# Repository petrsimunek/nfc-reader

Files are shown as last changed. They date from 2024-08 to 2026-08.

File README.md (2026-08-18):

# NFC Reader

NFC card reader with display, HID functionality and 3D printed case.

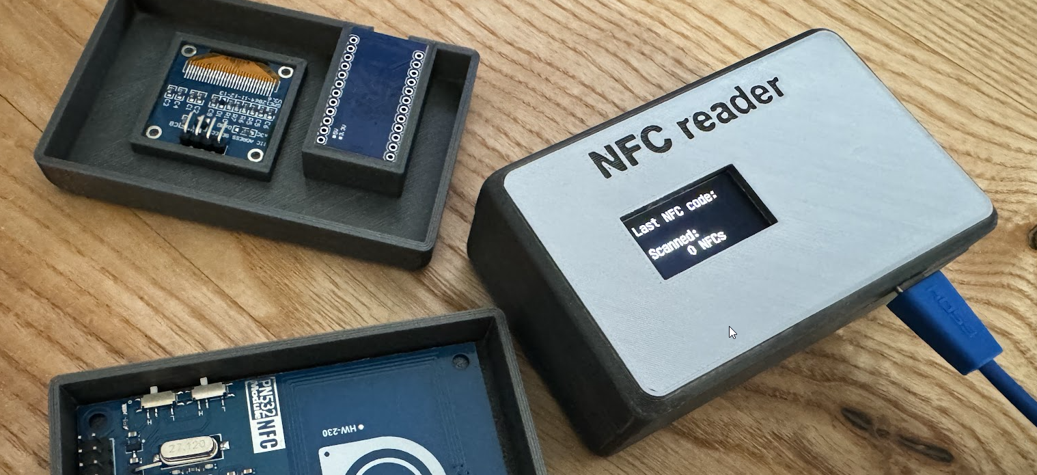
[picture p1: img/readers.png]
readers


## Motivation & backstory

User who is maintaining EV chargers asked for a simple tool, where he would be able to see card or chip number instantly. Chips comes sometimes with the number engraved on it, but some suppliers delivers cards without numbers.

So our user had to go to the EV charger, beep the card, go back to computer, and check the EV management for the "unauthorized card".

He asked for a solution, which would show him the number, and/or put the number to the computer.

I tried USB/NFC readers, or some flipper-like devices, but those were too complicated.

## How it works

Solution is built on arduino with NFC reader and simple display. User scan the card, and the number is displayed. The arduino has the HID feature enabled, so it directly inputs the card number to the connected computer, followed by TAB key.

SIMPLE!

## What is needed

- Arduino (pick model which supports HID feature - Arduino Pro Micro ATmega32U4 5V 16MHz) [link](https://dratek.cz/arduino/960-leonardo-pro-micro.html)
- PN532 NFC card reader [link](https://dratek.cz/arduino/2005-rfid-ic-ctecka-karet-13.56mhz-modul-pro-arduino-pn532-nfc.html)
- 1,3'' OLED display [link](https://dratek.cz/arduino-platforma/3181-iic-i2c-oled-1-3-displej-128x64-bily.html)
- microUSB cable

Plus

- Common tools + tool for soldering
- 3D printer
- Glue

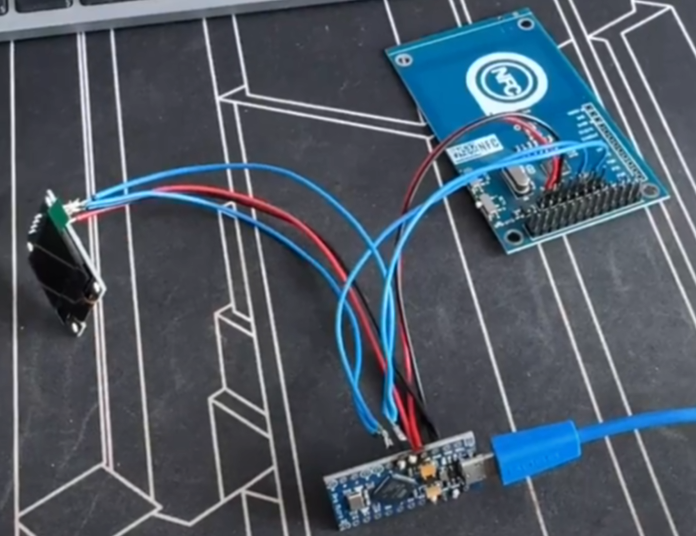
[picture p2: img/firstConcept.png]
first concept


## Wiring

Both the PN532 NFC reader and the OLED display share the same I2C bus on the Arduino Pro Micro. Set the PN532 module to **I2C mode** using its onboard switches before powering up.

### Arduino Pro Micro pins

| Function | Pin |
| --- | --- |
| SDA | **2** |
| SCL | **3** |
| VCC | **5V** |
| GND | **GND** |

### OLED display (I2C)

| OLED | Pro Micro |
| --- | --- |
| VCC | 5V |
| GND | GND |
| SDA | 2 (SDA) |
| SCK / SCL | 3 (SCL) |

### PN532 NFC reader (I2C)

| PN532 | Pro Micro |
| --- | --- |
| VCC | 5V |
| GND | GND |
| SDA | 2 (SDA) |
| SCL | 3 (SCL) |

Connect both modules in parallel on the I2C lines (SDA/SCL) and power rails (5V/GND). No other GPIO pins are used for the display or NFC reader.

## Change configuration

For any configuration changes you can run the `configurater/index.html` file. It is simple webpage with javascript inside. The javascript opens serial communication with the connected reader, and provides you simple GUI to change basic settings of the reader.

### Things you can configure

- enable/disable sending code to the computer
- keyboard mode
  - EN - use with top row keys
  - CS - use top row keys with Shift pressed (usable for national specific keyboard layouts)
  - NUMPAD - use numpad keys - might not work on laptops
- code mode - format of the code sent to the PC / shown on display
  - UID - full UID as hexadecimal (e.g. `04A3B21F`)
  - EVCH - full UID as decimal number
  - ADAM - first three UID bytes reversed into a 24-bit value, sent as decimal
  - CARD - sends UID, EVCH and ADAM one after another, with the configured key (TAB/ENTER/ESC) between them
- double read protection - if enabled, it won't allow you to read the same card again for 10 seconds - it avoids sending the same card twice to the PC
- enable/disable sending key after the code
- define the key which should be sent after the code
  - TAB
  - ESC
  - ENTER

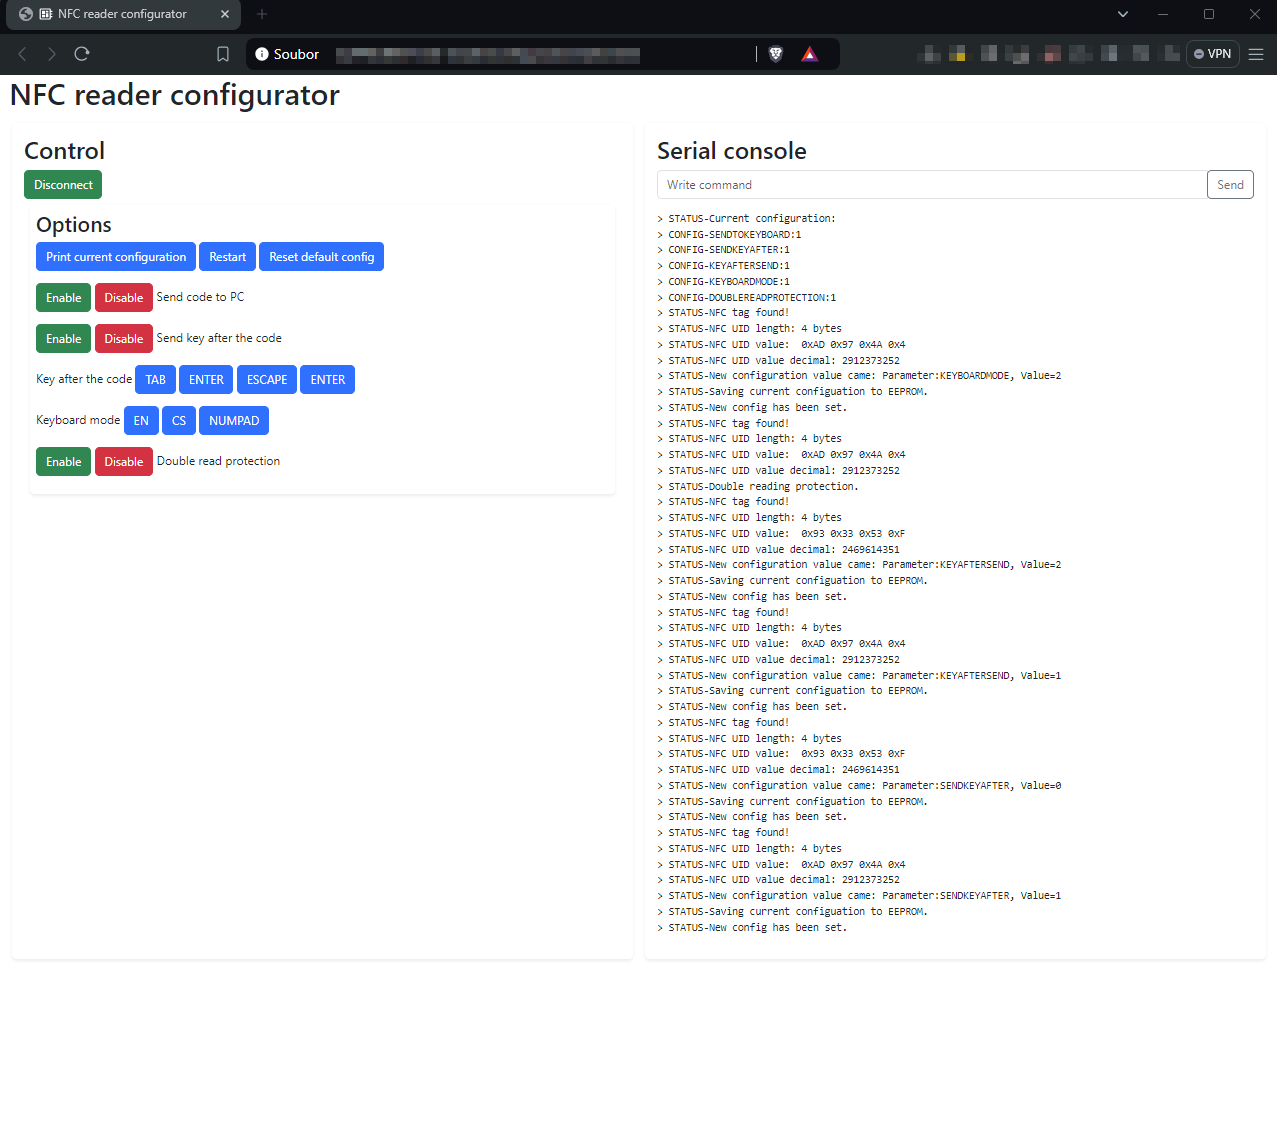
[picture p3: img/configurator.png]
configurator


## Case

Case can be printed on any 3D printer. There is no tricky part. Place the casing the text facing down on the heatbed.

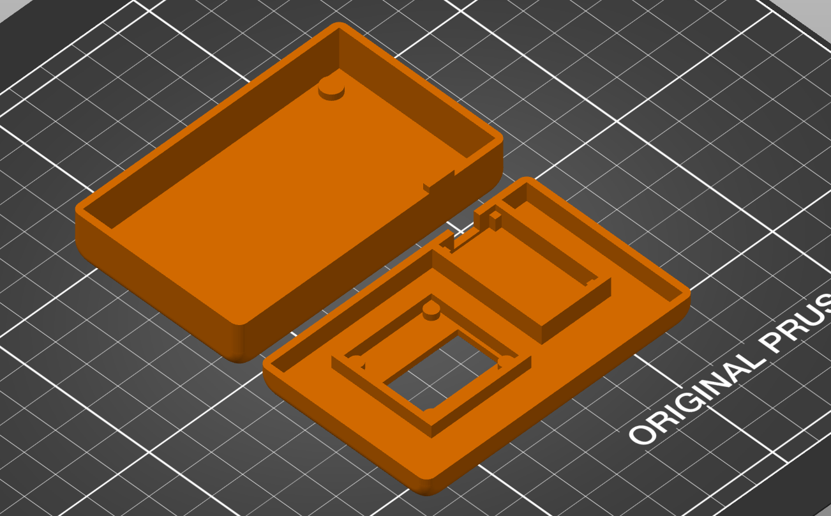
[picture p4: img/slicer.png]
slicer


Parameters for print:

- PLA (or any material) < tested on PLA
- no supports
- heating based on the material - default

For multicolor printing enable filament change in your slicer after the first layer.

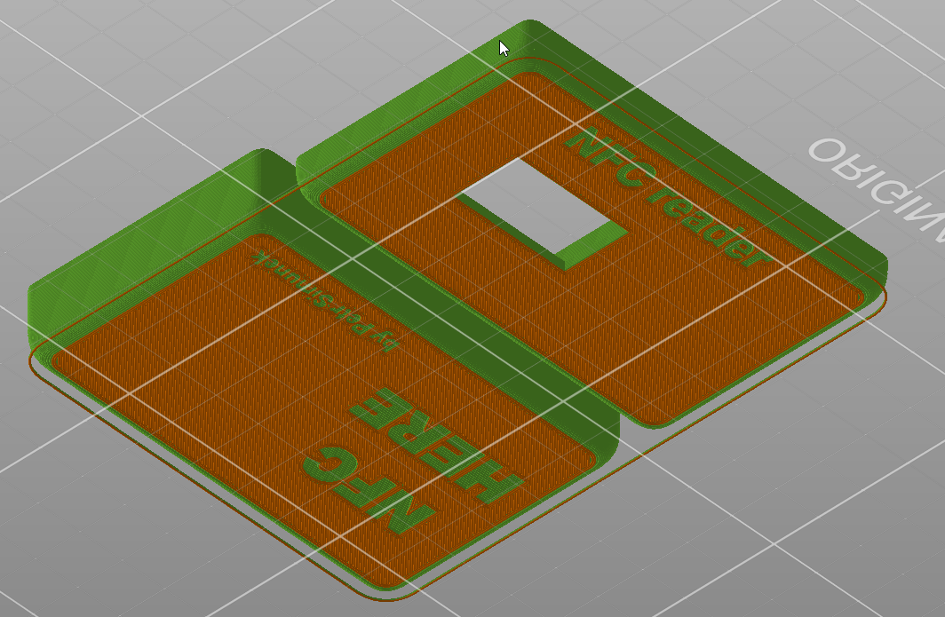
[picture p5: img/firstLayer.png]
first layer


## Troubleshooting

Basic debug can be done through serial console. Use serial monitor in arduino IDE, or putty.

If something do not work, check cabling, soldering, configuration through the configurator and num lock on your keyboard.

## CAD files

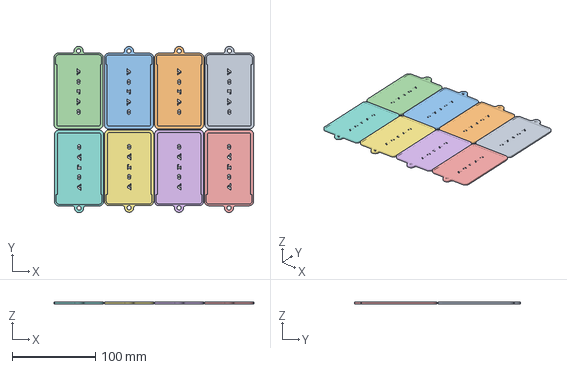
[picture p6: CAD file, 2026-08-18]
card_cover/cover.3mf
239.8 x 199.4 x 2.50 mm
Part Studio 1 - obal.stl x 2

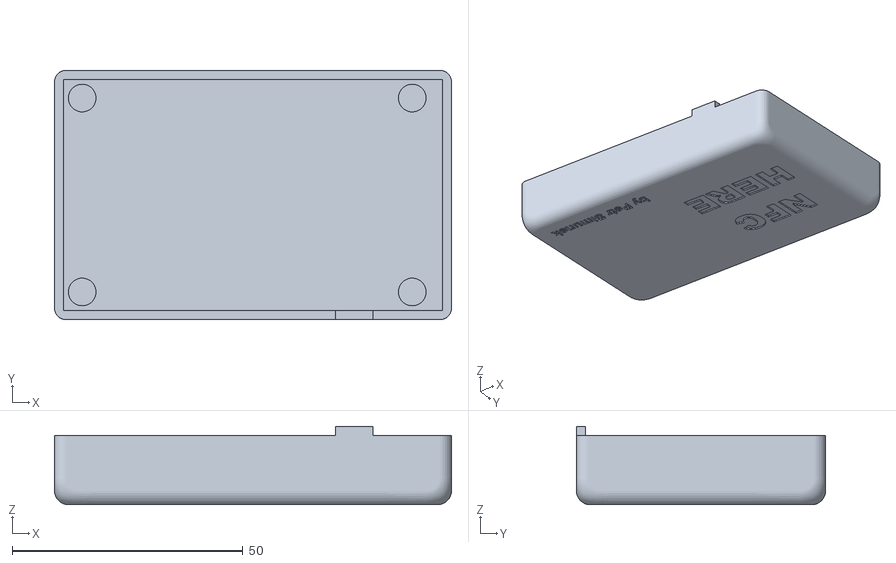
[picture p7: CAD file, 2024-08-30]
case/nfc_bottom_LP.stl
86.0 x 54.0 x 17.0

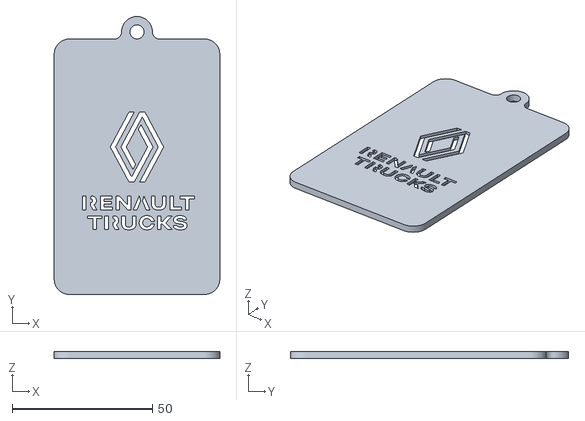
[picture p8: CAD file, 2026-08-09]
card_cover/cover-RT.stl
59.0 x 99.0 x 2.50

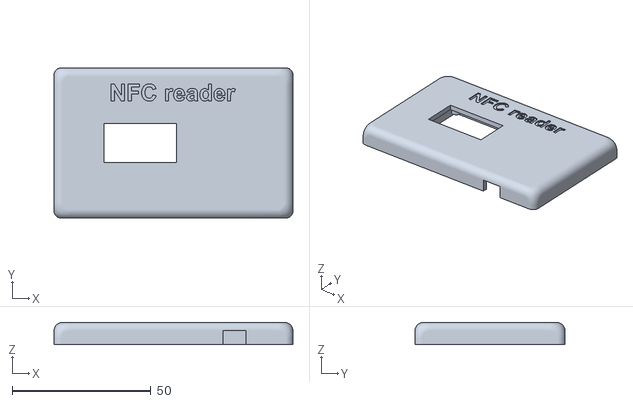
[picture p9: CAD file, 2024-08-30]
case/nfc_top_LP.stl
86.0 x 54.0 x 8.00

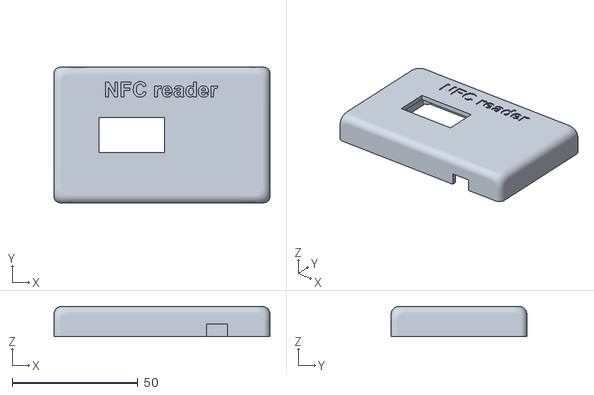
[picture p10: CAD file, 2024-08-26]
case/nfc_top.stl
86.0 x 54.0 x 12.0

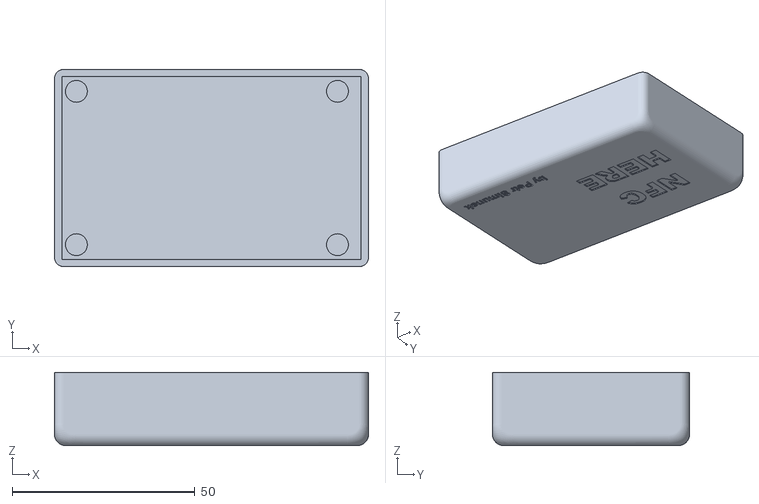
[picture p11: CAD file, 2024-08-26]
case/nfc_bottom.stl
86.0 x 54.0 x 20.0

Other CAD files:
card_cover/cover-VT.stl

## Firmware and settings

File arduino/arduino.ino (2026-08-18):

// include libs
#include <PN532_I2C.h>
#include <PN532.h>
#include <NfcAdapter.h>
#include <Keyboard.h>
#include <U8glib.h>
#include <avr/wdt.h>

// Version lives in configurator/version.js so the web UI and firmware share it.
#define EXPECTED_FIRMWARE_VERSION const char firmwareVersion[]
#if __has_include("../configurator/version.js")
#include "../configurator/version.js"
#elif __has_include("version.h")
#include "version.h"
#else
#include "version.js"
#endif
#undef EXPECTED_FIRMWARE_VERSION


// config structure
struct config
{
  bool sendToKeyboard;
  bool sendKeyAfter;
  int keyAfterSend;
  int keyboardMode;
  bool doubleReadProtection;
  int codeMode;               // 1 = UID, 2 = EVCH, 3 = ADAM, 4 = CARD
};
// global variable for configuration
config configuration;


// init I2C communication with NFC reader
PN532_I2C pn532i2c(Wire);
// init instance of NFC reader
PN532 nfc(pn532i2c);
// init OLED display
U8GLIB_SSD1306_128X64 myOled(U8G_I2C_OPT_NONE);
unsigned long previousMillis = 0;   // timer for loop

// init var for decimal value of the NFS tag
unsigned long decimalValue = 0;       // ID in dec
String stringDecimalValue;            // ID in string
String prevStringDecimalValue;        // previous ID in string
uint8_t lastUid[10] = { 0 };
uint8_t lastUidLength = 0;







void setup() {
  // keyboard HID start
  Keyboard.begin();
  // start serial communication
  Serial.begin(9600);
  // greetings on display
  myOled.firstPage();
  do {
    displayWriteInit();
  } while( myOled.nextPage() );
  // greetings on serial after a small delay
  delay(3000);
  Serial.print("STATUS-Hello! version ");
  Serial.println(firmwareVersion);
  // init configuration
  // check first run, then set the dafults and save it to the EEPROM
  if (isFirstRun()) {
    Serial.println("STATUS-First run, writing the defaults to EEPROM.");
    setDefaultConfig();
    saveConfig();
  } else {
    loadConfig();
  }
  printCurrentConfig();
  // start NFC communication
  nfc.begin();
  // set max no of NFC read attempts
  nfc.setPassiveActivationRetries(0xFF);
  // configure NFC for reading tags
  nfc.SAMConfig();
  // debug info for user
  Serial.println("STATUS-Ready");
}







void loop() {
  // current time for timer
  unsigned long currentMillis = millis();
  //read NFC in interval
  if (currentMillis - previousMillis >= (2000)) {
    // update prev. timer
    previousMillis = currentMillis;
    // read NFC
    readNfc();
    // rewrite display
    // refresh display
    myOled.firstPage();
    do {
      displayWrite();
    } while( myOled.nextPage() );
  }
  //check new commands
  checkSerialCommands();
}







// checks serial commands
void checkSerialCommands() {
    // check
    if (Serial.available() > 0) {
        String command = Serial.readStringUntil('\n');
        command.trim();
        // run function based on command prefix
        if (command.indexOf("CONFIG-") == 0) newConfig(command);
        else if (command == "SHOWCONFIG") printCurrentConfig();
        else if (command == "SHOWNFCLAST") Serial.println(prevStringDecimalValue);
        else if (command == "RESTART") restart();
        else if (command == "RESET") reset();
        else Serial.println("Unknown command prefix");
    }
}

// function for restarting arduino
void restart() {
  Serial.println("STATUS-Restarting device");
  wdt_enable(WDTO_15MS);
  while (1) {
    // infinite loop for restarting the arduino
  }
}

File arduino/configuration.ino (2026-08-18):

#include <EEPROM.h>

bool defaultSendToKeyboard = true;
bool defaultSendKeyAfter = true;
int defaultKeyAfterSend = 1;
int defaultKeyboardMode = 1;
bool defaultDoubleReadProtection = true;
int defaultCodeMode = 2; // EVCH

// EEPROM is empty?
bool isFirstRun() {
  return EEPROM.read(0) == 0xFF;
}

// keep config values in valid ranges (e.g. after firmware upgrade)
void sanitizeConfig() {
  if (configuration.codeMode < 1 || configuration.codeMode > 4) {
    configuration.codeMode = defaultCodeMode;
  }
  if (configuration.keyboardMode < 1 || configuration.keyboardMode > 3) {
    configuration.keyboardMode = defaultKeyboardMode;
  }
  if (configuration.keyAfterSend < 1 || configuration.keyAfterSend > 3) {
    configuration.keyAfterSend = defaultKeyAfterSend;
  }
  // EEPROM bools can be 0xFF after struct changes; treat garbage as default
  if (configuration.doubleReadProtection != 0 && configuration.doubleReadProtection != 1) {
    configuration.doubleReadProtection = defaultDoubleReadProtection;
  }
  if (configuration.sendToKeyboard != 0 && configuration.sendToKeyboard != 1) {
    configuration.sendToKeyboard = defaultSendToKeyboard;
  }
  if (configuration.sendKeyAfter != 0 && configuration.sendKeyAfter != 1) {
    configuration.sendKeyAfter = defaultSendKeyAfter;
  }
}

void loadConfig() {
  EEPROM.get(1, configuration);
  sanitizeConfig();
}

// function for printing current configuration to serial console
void printCurrentConfig() {
  Serial.println("STATUS-Current configuration:");
  Serial.print("STATUS-VERSION:");
  Serial.println(firmwareVersion);
  Serial.print("CONFIG-SENDTOKEYBOARD:");
  Serial.println(configuration.sendToKeyboard);
  Serial.print("CONFIG-SENDKEYAFTER:");
  Serial.println(configuration.sendKeyAfter);
  Serial.print("CONFIG-KEYAFTERSEND:");
  Serial.println(configuration.keyAfterSend);
  Serial.print("CONFIG-KEYBOARDMODE:");
  Serial.println(configuration.keyboardMode);
  Serial.print("CONFIG-DOUBLEREADPROTECTION:");
  Serial.println(configuration.doubleReadProtection);
  Serial.print("CONFIG-CODEMODE:");
  Serial.println(configuration.codeMode);
}

// set default values to global configuration variable
void setDefaultConfig() {
  configuration.sendToKeyboard = defaultSendToKeyboard;
  configuration.sendKeyAfter = defaultSendKeyAfter;
  configuration.keyAfterSend = defaultKeyAfterSend;
  configuration.keyboardMode = defaultKeyboardMode;
  configuration.doubleReadProtection = defaultDoubleReadProtection;
  configuration.codeMode = defaultCodeMode;
}

// save the current configuration to the EEPROM
void saveConfig() {
  Serial.println("STATUS-Saving current configuation to EEPROM.");
  EEPROM.write(0, 0x00);      // set first block of EEPROM to 0 to indicate, that the configuration is there
  EEPROM.put(1, configuration);
}

// reset to defaults
void reset() {
  Serial.println("STATUS-Reseting configuration");
  EEPROM.write(0, 0xFF);  // set memory indicator
  restart();
}


void newConfig(String command) {
  Serial.print("STATUS-New configuration value came: ");
  // get rest of the command
  String remaining = command.substring(7);
  remaining.trim();
  // find colon
  int colonIndex = remaining.indexOf(':');
  if (colonIndex != -1) {
    // split to parameter and value
    String parameter = remaining.substring(0, colonIndex);
    String value = remaining.substring(colonIndex + 1);
    parameter.trim();
    value.trim();
    // serial
    Serial.print("Parameter:");
    Serial.print(parameter);
    Serial.print(", Value=");
    Serial.println(value);
    // set parameter
    if (parameter == "SENDTOKEYBOARD"){configuration.sendToKeyboard = value.toInt();}
    else if (parameter == "SENDKEYAFTER"){configuration.sendKeyAfter = value.toInt();}
    else if (parameter == "KEYAFTERSEND"){configuration.keyAfterSend = value.toInt();}
    else if (parameter == "KEYBOARDMODE"){configuration.keyboardMode = value.toInt();}
    else if (parameter == "DOUBLEREADPROTECTION"){configuration.doubleReadProtection = value.toInt();}
    else if (parameter == "CODEMODE"){configuration.codeMode = value.toInt();}
    else {Serial.println("Unknown parameter.");}
    sanitizeConfig();
    // save config to EEPROM
    saveConfig();
    Serial.println("STATUS-New config has been set.");
  }
  else {
    Serial.println("Colon not found, config command corrupted");
  }
}

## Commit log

2024-08-26 init commit
    [nfc_bottom.stl, nfc_top.stl]
2024-08-30 new design of case, save space with lower profile
    [nfc_bottom_LP.stl, nfc_top_LP.stl]
2024-08-30 case information
2026-08-08 fixed readme and wiring
2026-08-08 added adam format switch
2026-08-09 cover for hang employee cards
    [cover-RT.stl, cover-VT.stl, cover.3mf]
